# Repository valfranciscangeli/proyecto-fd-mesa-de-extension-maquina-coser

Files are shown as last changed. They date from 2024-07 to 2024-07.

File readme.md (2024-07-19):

# Proyecto de Mesa de Extensión para Máquina de Coser Casera

Este repositorio contiene el proyecto final del curso de Fabricación Digital. Se diseñó una mesa de extensión específicamente para la máquina de coser casera Janome Sakura 95.

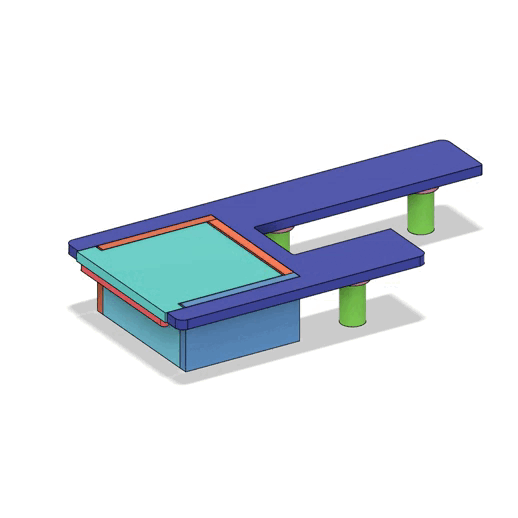
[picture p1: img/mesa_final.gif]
mesa completa


Las explicaciones sobre las piezas se basan en el documento `Piezas.pdf`, que muestra el número de pieza de cada parte del diseño.

## Resultado
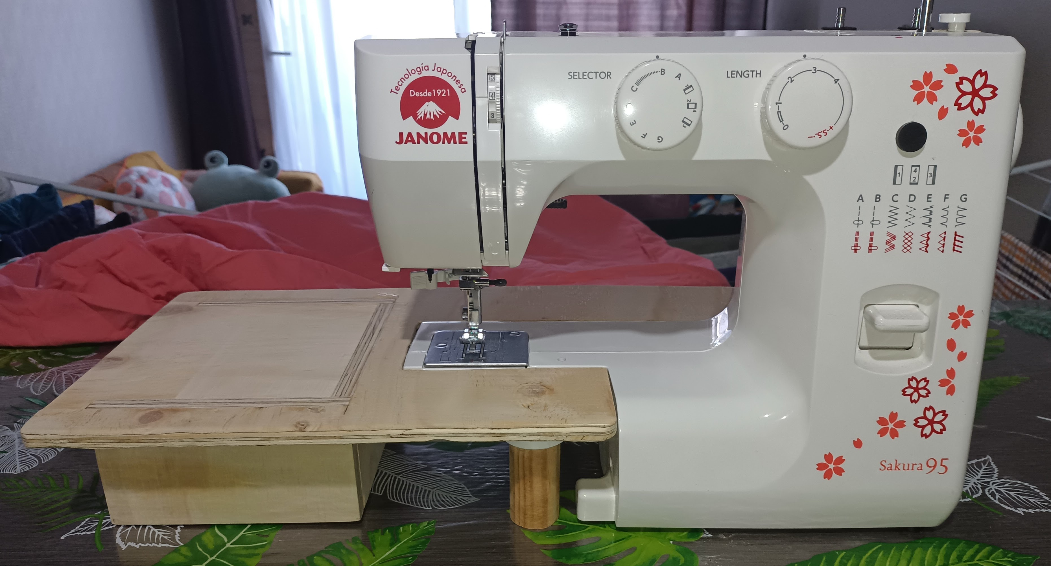
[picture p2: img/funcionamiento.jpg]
adaptador


## Archivos del Proyecto

En el repositorio se encuentran las siguientes carpetas y archivos:

- **origen**
  - **ensamble**
    - `proyecto_final`: archivo del ensamble final que referencia al resto de archivos.
    - **ensamble_cajon**: carpeta que contiene imágenes que muestran cómo se acoplan las piezas del cajón.
  - **fdm**: contiene los archivos de las piezas que se fabricaron con impresión 3D
    - **adaptador pata**: carpeta que contiene los archivos de la pieza número 8
    - **tirador**: carpeta que contiene los archivos de la pieza número 9
  - **img**: carpeta con archivos de imágenes usadas en este documento.
  - **router_cnc**: contiene los archivos de las piezas fabricadas por corte en router CNC
    - **cajon bottom**: carpeta que contiene los archivos de la pieza número 2
    - **cortes**: carpeta que contiene archivos de corte de las piezas del cajón base
    - **frontal**: carpeta que contiene los archivos de la pieza número 4
    - **lado 1**: carpeta que contiene los archivos de la pieza número 1
    - **lado 2**: carpeta que contiene los archivos de la pieza número 6
    - **mesa top**: carpeta que contiene los archivos de la pieza número 7
    - **posterior**: carpeta que contiene los archivos de la pieza número 3
    - **tapa**: carpeta que contiene los archivos de la pieza número 5
  - `Piezas.pdf`: archivo que muestra el número y tabla de piezas generada por el software Fusion360.

## Diseño

Se realizó el diseño del proyecto en el software Fusion 360. Los archivos se encuentran ordenados en las carpetas descritas anteriormente.

Se diseñó una mesa a medida de la máquina de coser Janome Sakura 95. El diseño contempla un cajón en la base que permite guardar accesorios de la máquina e implementos de costura.

Se numeran las piezas como sigue:

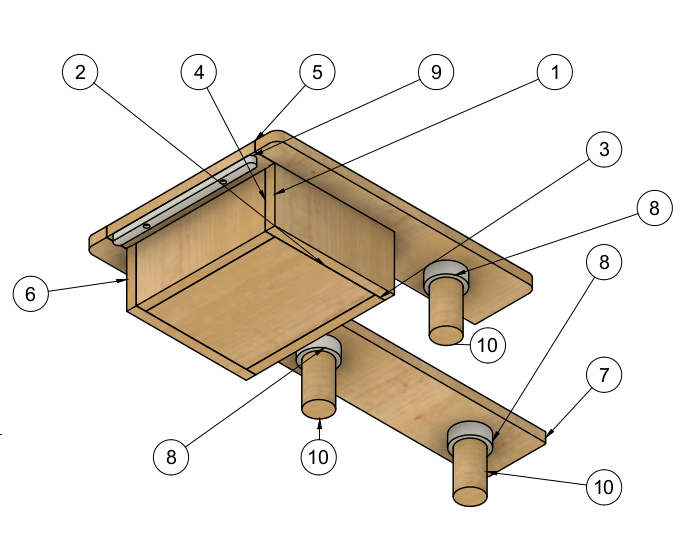
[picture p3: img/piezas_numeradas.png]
Tabla de piezas, materiales y procesos


## Piezas, Materiales y Procesos de Fabricación

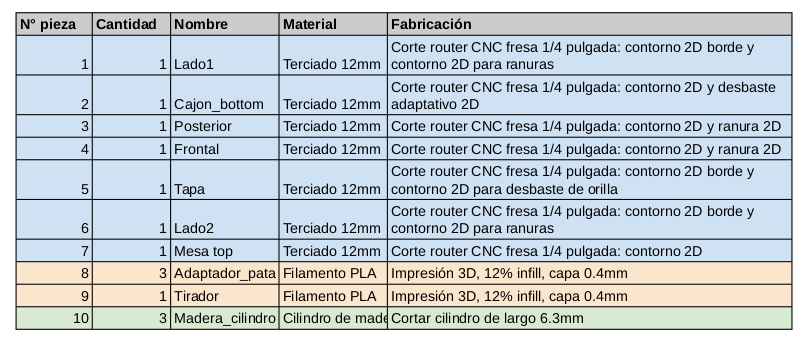
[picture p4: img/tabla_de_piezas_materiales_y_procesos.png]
Tabla de piezas, materiales y procesos


## Costos

Para realizar toda la estructura de la mesa se necesita:
- Una plancha de terciado de 12mm. Se necesita solo la mitad de la plancha estándar de 1,2x2,4m. El valor aproximado es de <a href="https://www.imperial.cl/terciados/terciado-estructural-12mm-120x240mt/product/76017">17.990 CLP</a>.
- 5 tornillos de 3x10mm. Un pack de 20 unidades costó 750 CLP.
- Filamento PLA. Las 4 piezas impresas en 3D utilizan 41g de filamento en total. Calculando en base a la referencia de <a href="https://cicla3d.cl/products/cicla-pla?variant=46081855357178">12.390 CLP</a> por Kg, el costo total de la impresión es de 508 CLP.
- Cola fría de madera, como pegamento. Se utiliza una cantidad muy pequeña, pero un sachet de 500g se encuentra a <a href="https://www.idepal.cl/cola-fria-doy-pack-500gr">1.990 CLP</a>.
- Barra de madera (cilindro) de 30mm. Se utilizó en total menos de 25cm en total de la barra. La única referencia de precio encontrada fue de de 2 barras de 30mmx1mt a <a href="https://articulo.mercadolibre.cl/MLC-536082012-barras-de-madera-de-coihue-lisas-30mm-x-1mt-2-u-_JM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">12.800 CLP</a>, sin embargo, se puede reutilizar un palo de escoba o cortina (mi caso) o imprimir la pieza en 3D.

## Ensamble

El ensamble general se encuentra en el archivo de `proyecto_final`.

Paso a paso:
1. Ensamblar la caja base uniendo con cola fría las piezas 1, 2, 3, 4 y 6. Deben calzar las ranuras en los bolsillos. Se adjuntan distintas vistas del proceso.
Vista superior 1.
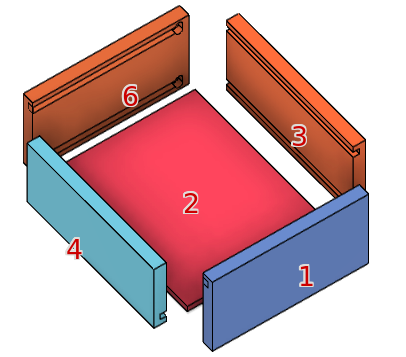
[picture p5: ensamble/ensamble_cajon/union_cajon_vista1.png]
Unión de piezas de cajón base. Vista superior 1.

Vista superior 2.
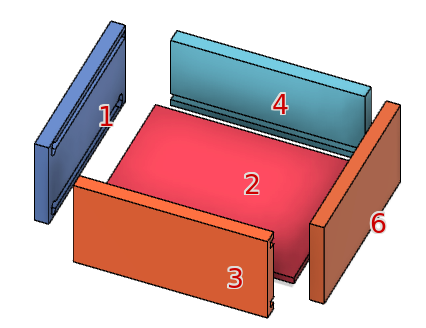
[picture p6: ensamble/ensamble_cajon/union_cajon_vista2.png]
Unión de piezas de cajón base. Vista superior 2.

Vista inferior.
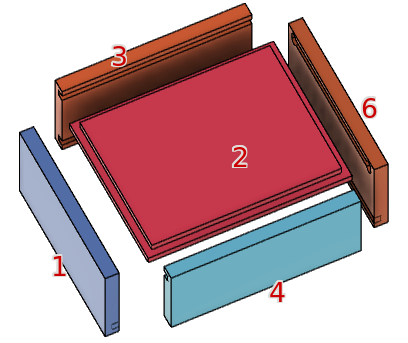
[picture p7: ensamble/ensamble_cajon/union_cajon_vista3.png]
Unión de piezas de cajón base. Vista inferior.

2. Unir a la parte superior de la caja base del paso 1 la pieza 7. Se puede pegar solo con cola fría o agregar clavos (en mi caso no fue necesario).
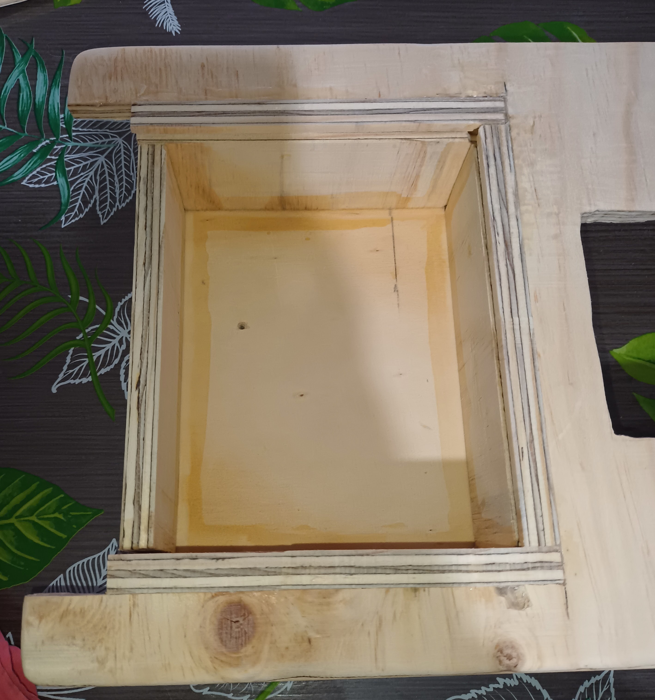
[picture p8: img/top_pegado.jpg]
Pegado de top


3. Unir con tornillos de 3x10mm la pieza 9 a la parte inferior de la pieza 5.
El tirador debe ir con el orificio de 2 profundidades hacia arriba, para ahí insertar el tornillo.
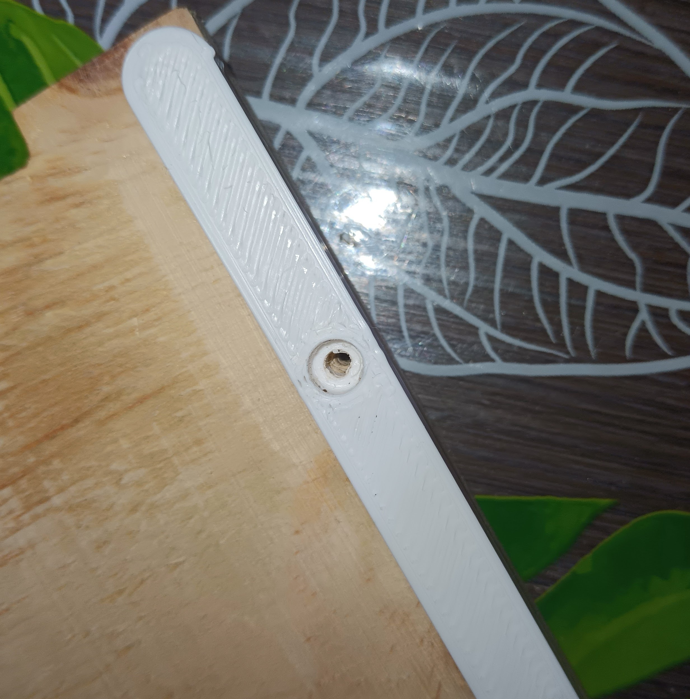
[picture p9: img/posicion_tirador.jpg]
Unión de tirador

Tornillo 3x10mm.
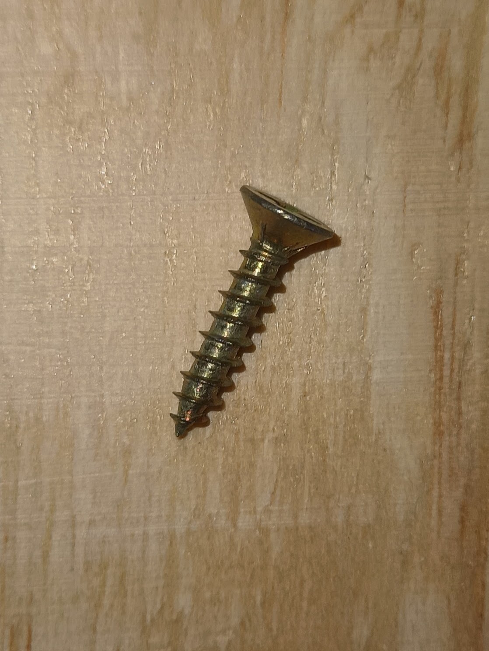
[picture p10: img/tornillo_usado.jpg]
Tornillo usado

Así queda:
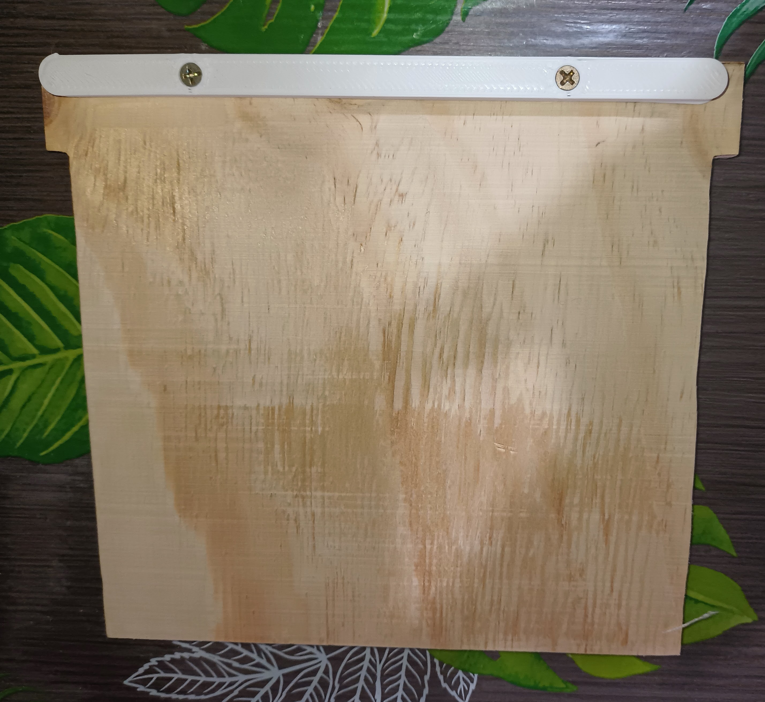
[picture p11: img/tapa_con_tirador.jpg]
Tapa

4. Unir con tornillos de 3x10mm las piezas 8 a la parte inferior de la pieza 7, siguiendo la distancia del diseño del proyecto. Cortar un cilindro de madera de 30mm de diámetro en 3 piezas de largo 6.3mm, para utilizar como pieza 10. Luego insertar estas piezas en cada adaptador (pieza 8).
Adaptador atornillado:
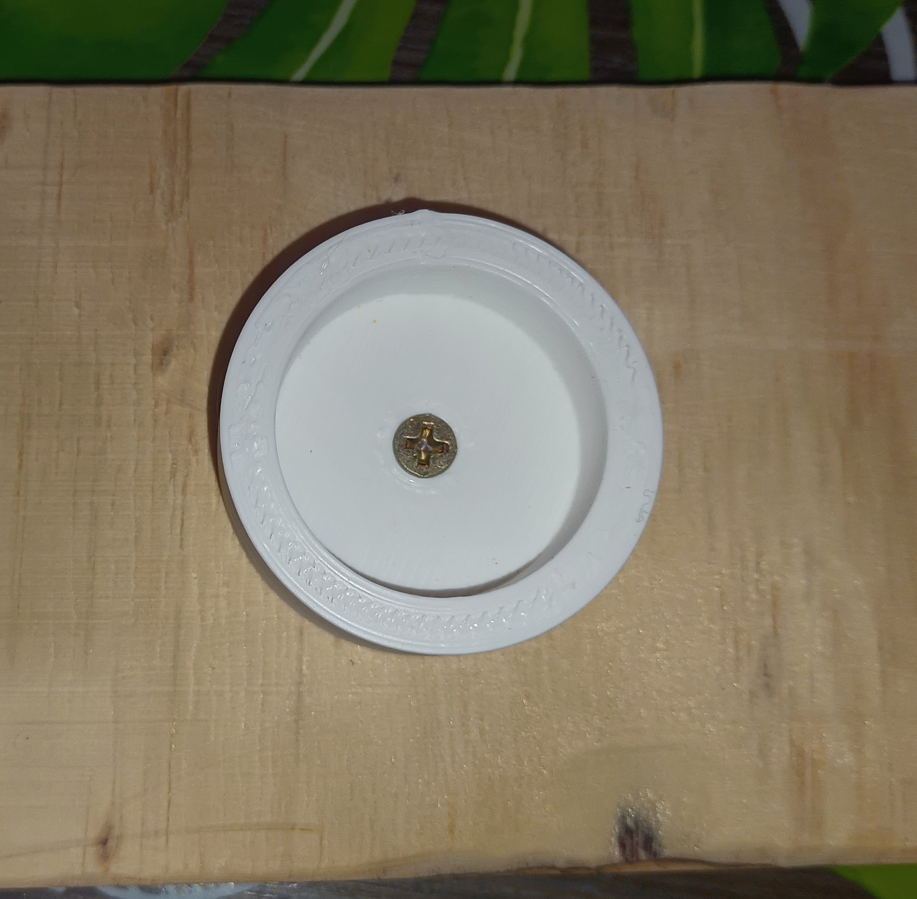
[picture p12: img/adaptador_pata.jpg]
Adaptador

Agregar pieza 10:
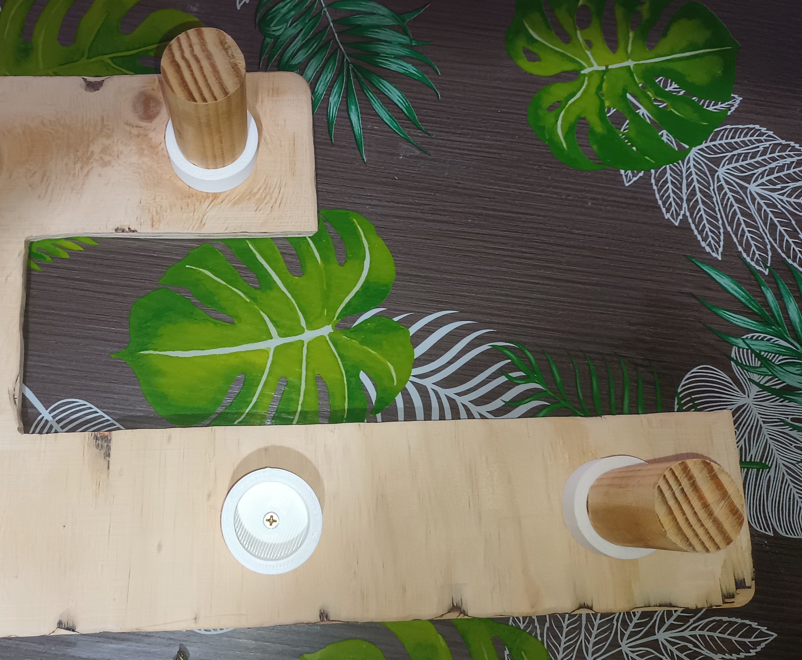
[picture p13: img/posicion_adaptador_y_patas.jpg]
Adaptador

5. Deslizar la pieza 9 con la pieza 5 hacia abajo por las ranuras del cajón base armado en el paso 1.
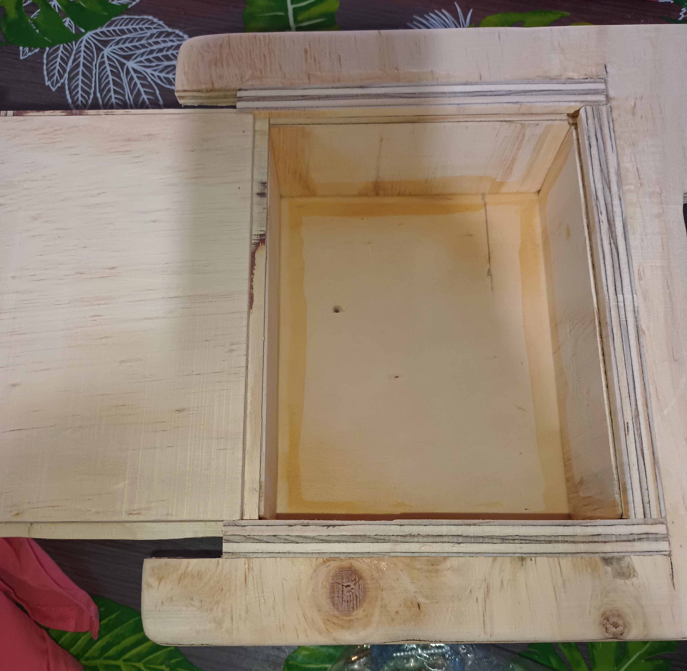
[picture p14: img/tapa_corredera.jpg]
Tapa

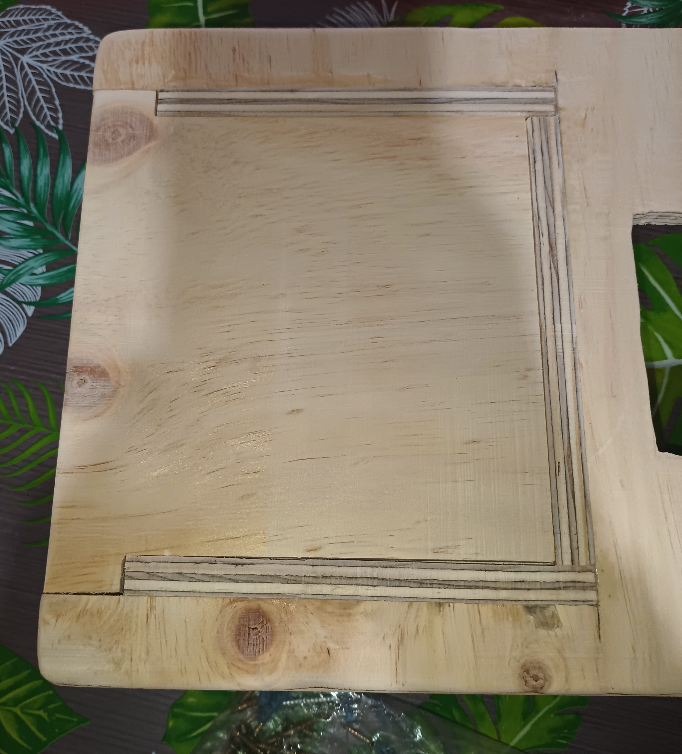
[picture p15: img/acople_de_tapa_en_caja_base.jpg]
Acople


6. Lijar toda la pieza con lija de madera hasta que la superficie sea suave, para no enganchar la tela.
7. Opcional: agregar bases de goma antideslizantes.
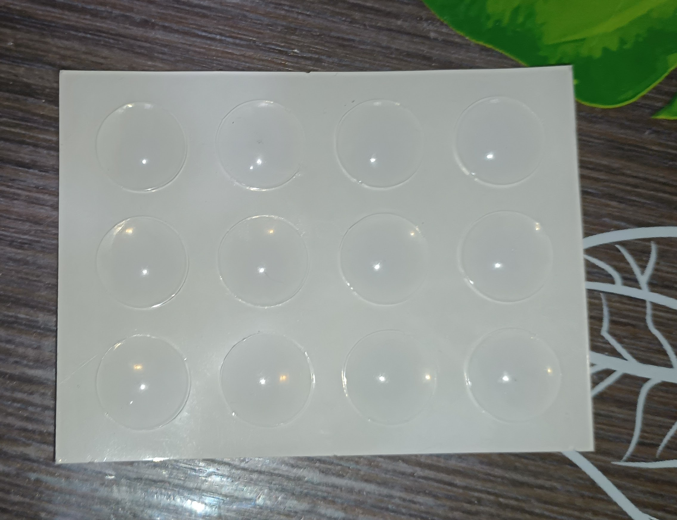
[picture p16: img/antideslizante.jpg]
Gomas antideslizantes

Patas:
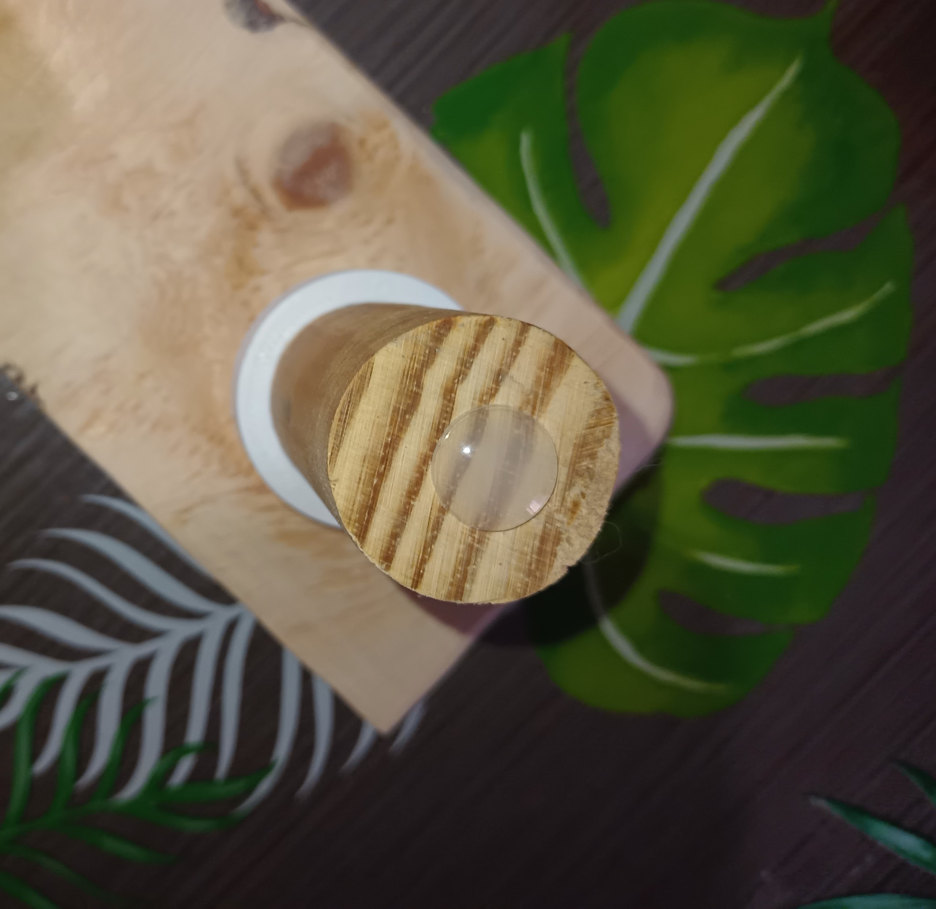
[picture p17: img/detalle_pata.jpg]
Patas

Cajón vista inferior:
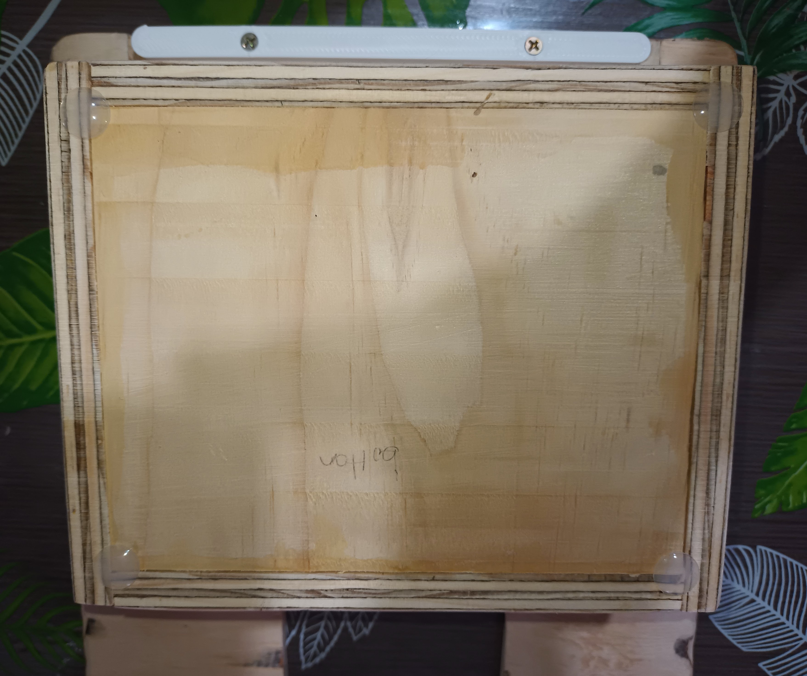
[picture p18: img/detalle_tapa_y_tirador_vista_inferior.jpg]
Cajón vista inferior


## Sugerencias para mejorar el proyecto
- Cortar la pieza 7 en una lámina de acrílico para tener una superficie completamente lisa y una mesa más estética.
- Agregar un soporte para cono de hilo de tamaño normal en la parte trasera de la pieza 7.

## Material Extra

En la carpeta img se adjuntan imágenes del proceso incluyendo las que se encuentran en este archivo.

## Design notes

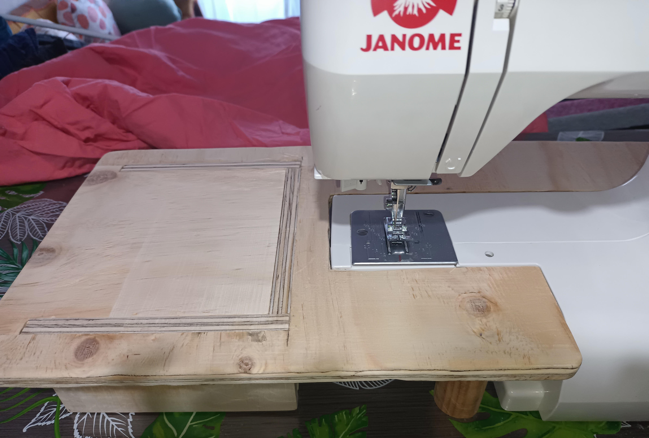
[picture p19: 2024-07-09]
img/detalle_acople.jpg

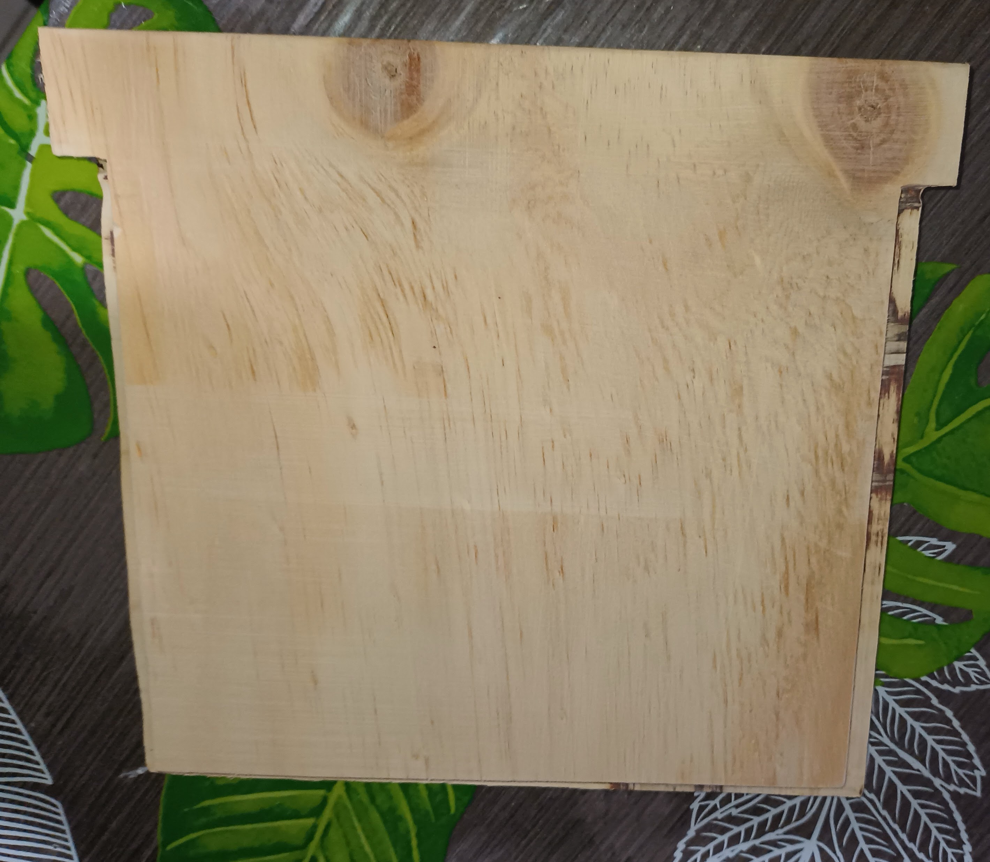
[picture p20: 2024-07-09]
img/tapa.jpg

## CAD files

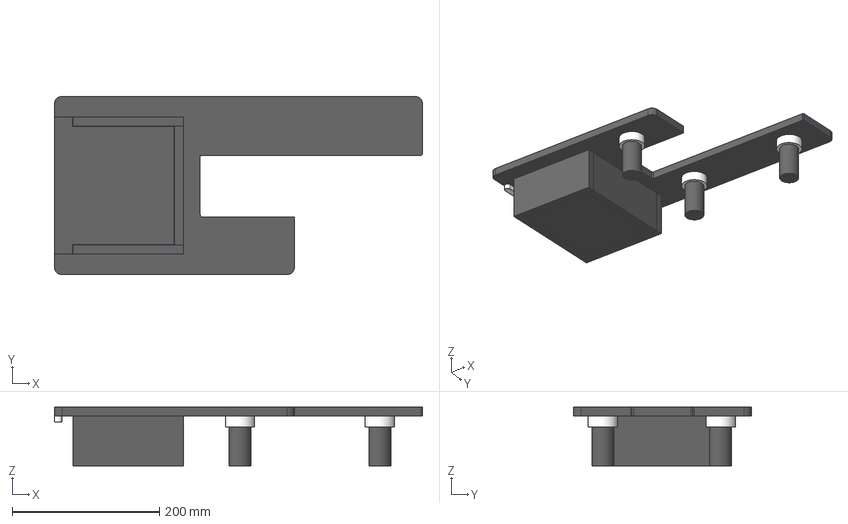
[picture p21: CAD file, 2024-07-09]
ensamble/proyecto_final/ProyectoFinal v28.step
500.0 x 242.0 x 80.0 mm
lado1
cajon_bottom
posterior
frontal
tapa
lado2
mesa top
adaptador_pata x 3
tirador
madera_cilindro x 3

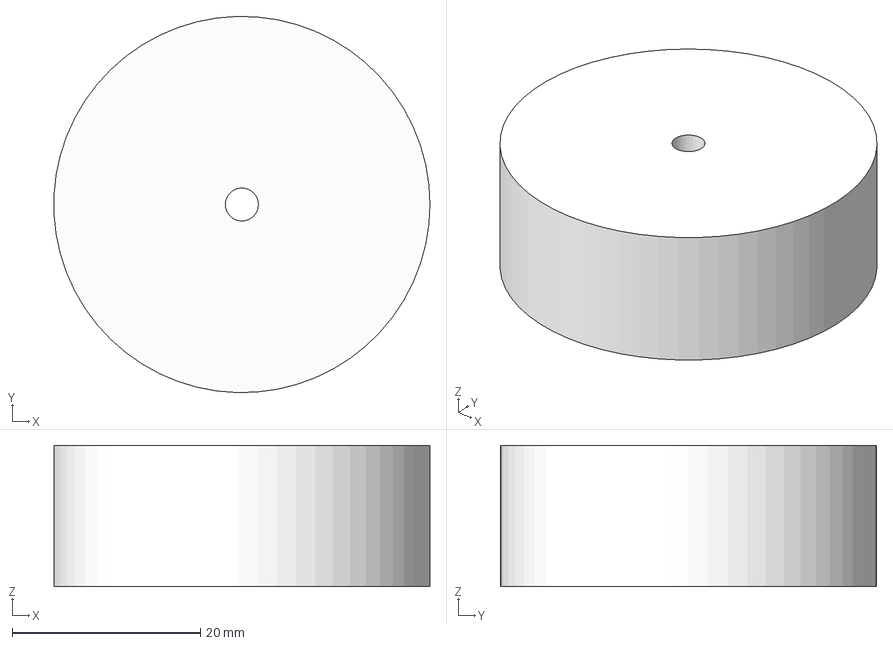
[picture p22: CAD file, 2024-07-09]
fdm/adaptador pata/adaptador_pata v7.step
40.0 x 40.0 x 15.0 mm

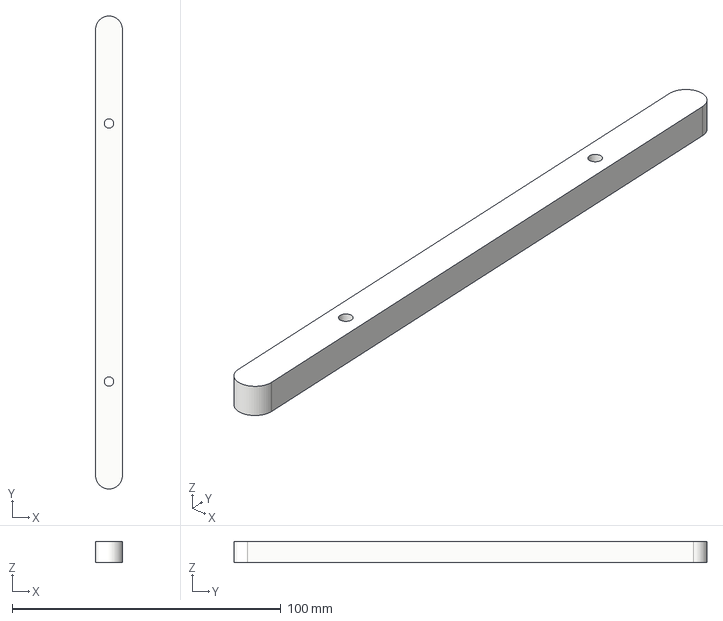
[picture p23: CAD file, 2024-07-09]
fdm/tirador/tirador v1.step
10.0 x 176.1 x 8.00 mm

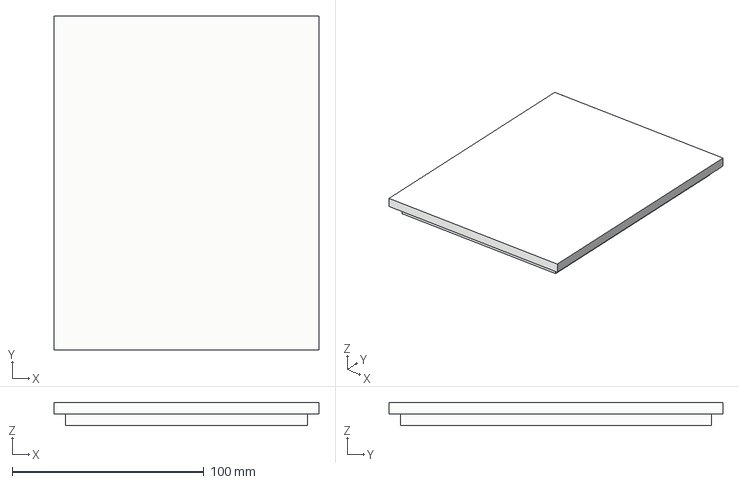
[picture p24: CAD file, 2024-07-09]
router_cnc/cajon bottom/cajon_bottom v3.step
138.0 x 174.0 x 12.0 mm

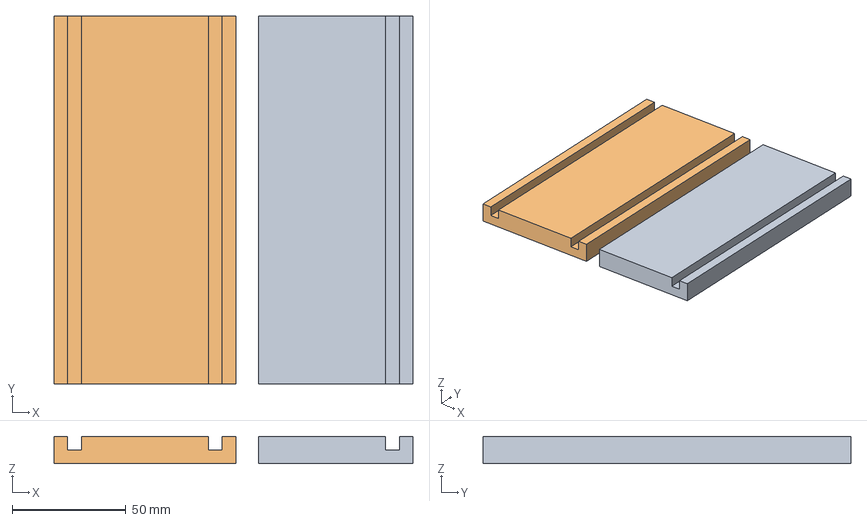
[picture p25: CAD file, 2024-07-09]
router_cnc/cortes/corte 1/corte cajón v11.step
158.0 x 162.0 x 12.0 mm
frontal
posterior

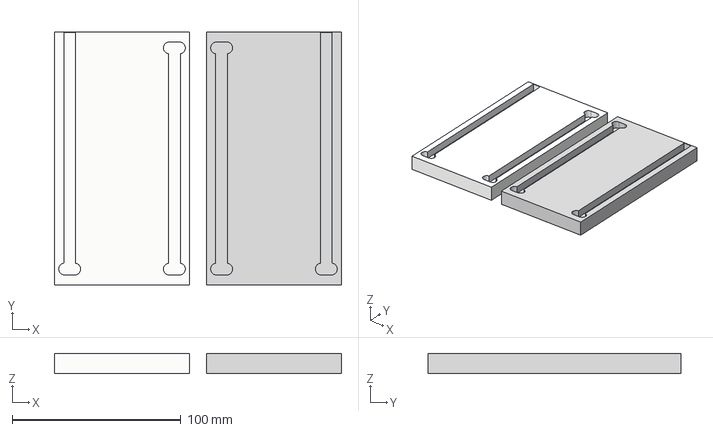
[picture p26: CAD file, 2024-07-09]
router_cnc/cortes/corte 3/corte cajón 3 v7.step
170.0 x 150.0 x 12.0 mm
lado1
lado2

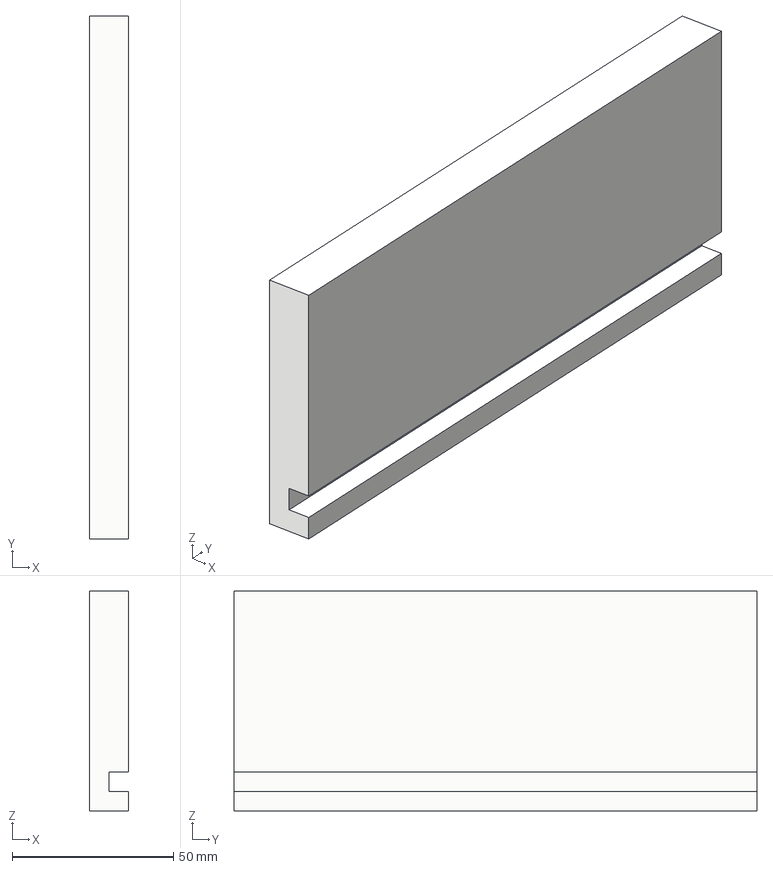
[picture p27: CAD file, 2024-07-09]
router_cnc/frontal/frontal v1.step
12.0 x 162.0 x 68.0 mm

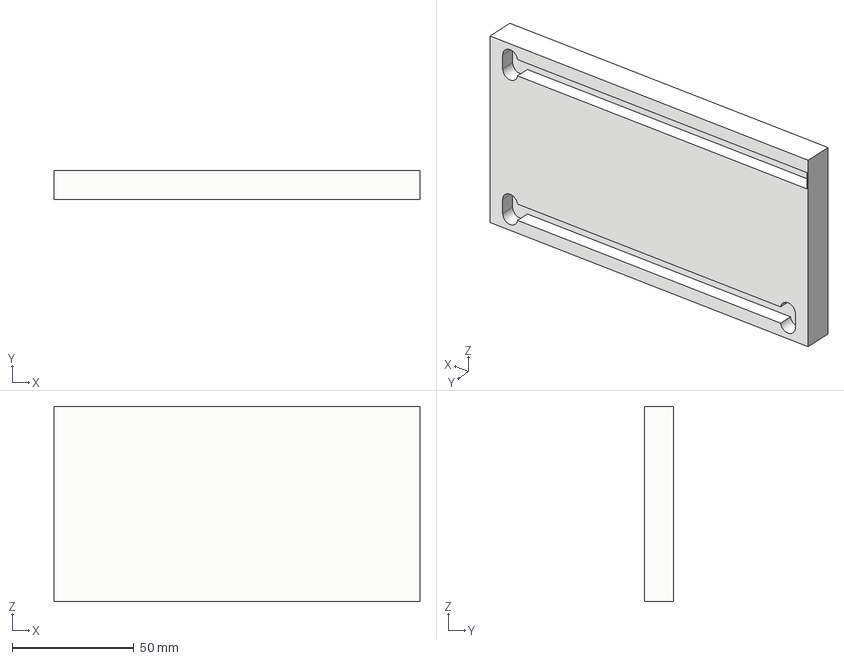
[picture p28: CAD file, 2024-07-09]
router_cnc/lado 1/lado1 v4.step
150.0 x 12.0 x 80.0 mm

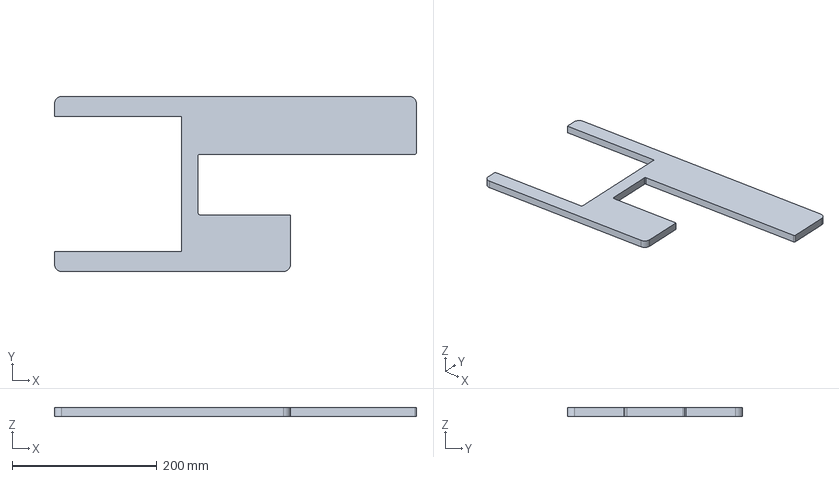
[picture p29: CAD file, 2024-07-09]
router_cnc/mesa top/mesa top v9.step
500.0 x 242.0 x 12.0 mm

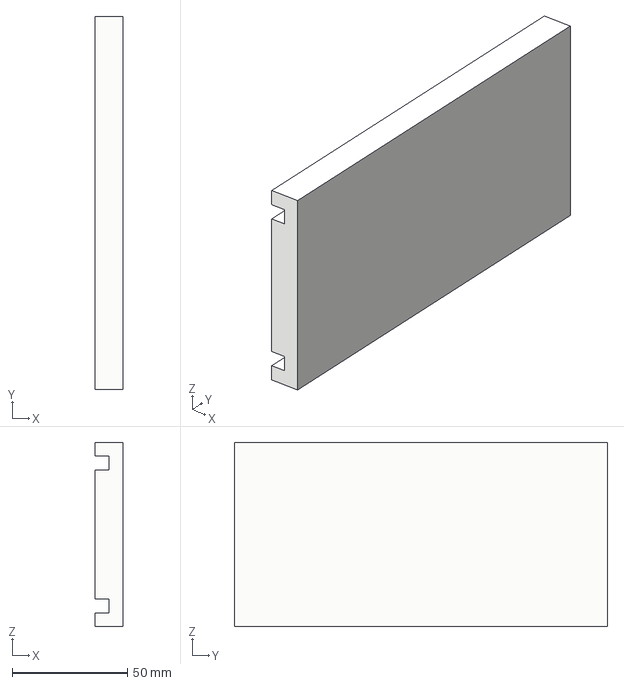
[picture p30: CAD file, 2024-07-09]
router_cnc/posterior/posterior v1.step
12.0 x 162.0 x 80.0 mm

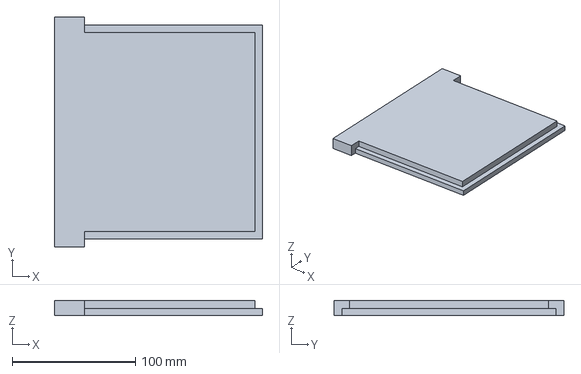
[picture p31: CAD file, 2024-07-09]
router_cnc/tapa/tapa v6.step
168.5 x 186.1 x 12.0 mm

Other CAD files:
router_cnc/cortes/corte 2/corte cajón 2 v13.step
router_cnc/lado 2/lado2 v5.step
ensamble/proyecto_final/ProyectoFinal v28.f3z
fdm/adaptador pata/adaptador_pata v7.f3d
fdm/tirador/tirador v1.f3d
router_cnc/cajon bottom/cajon_bottom v3.f3d
router_cnc/cortes/corte 1/corte cajón v11.f3z
router_cnc/cortes/corte 2/corte cajón 2 v13.f3z
router_cnc/cortes/corte 3/corte cajón 3 v7.f3z
router_cnc/frontal/frontal v1.f3d
router_cnc/lado 1/lado1 v4.f3d
router_cnc/lado 2/lado2 v5.f3d
router_cnc/mesa top/mesa top v9.f3d
router_cnc/posterior/posterior v1.f3d
router_cnc/tapa/tapa v6.f3d

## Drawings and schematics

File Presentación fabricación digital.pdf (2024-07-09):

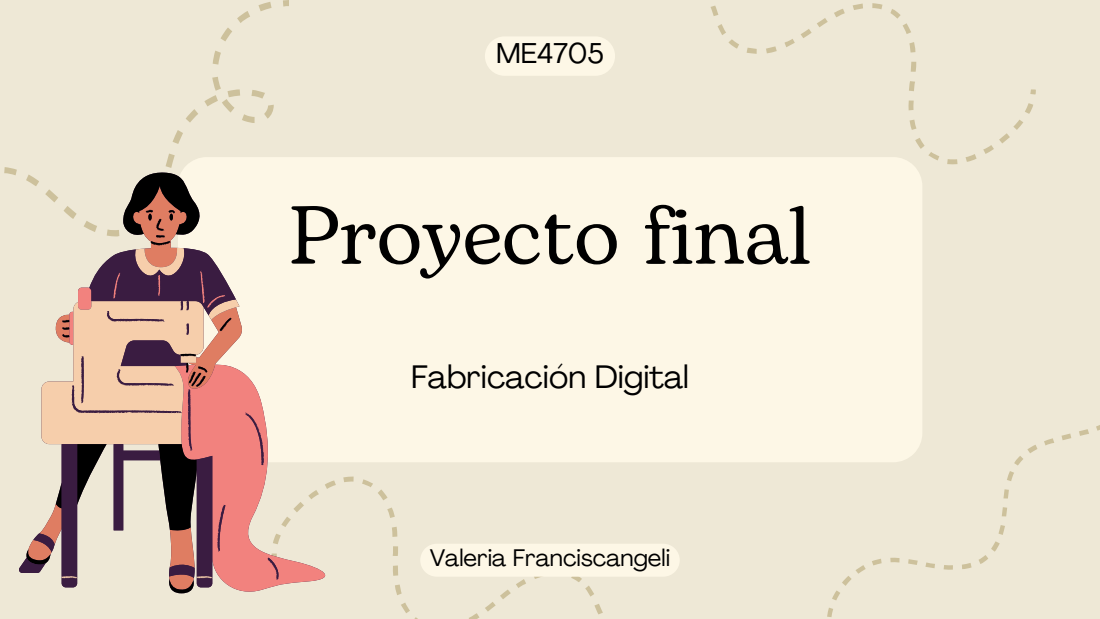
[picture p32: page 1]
Proyecto final; Fabricación Digital; Valeria Franciscangeli

# Problema

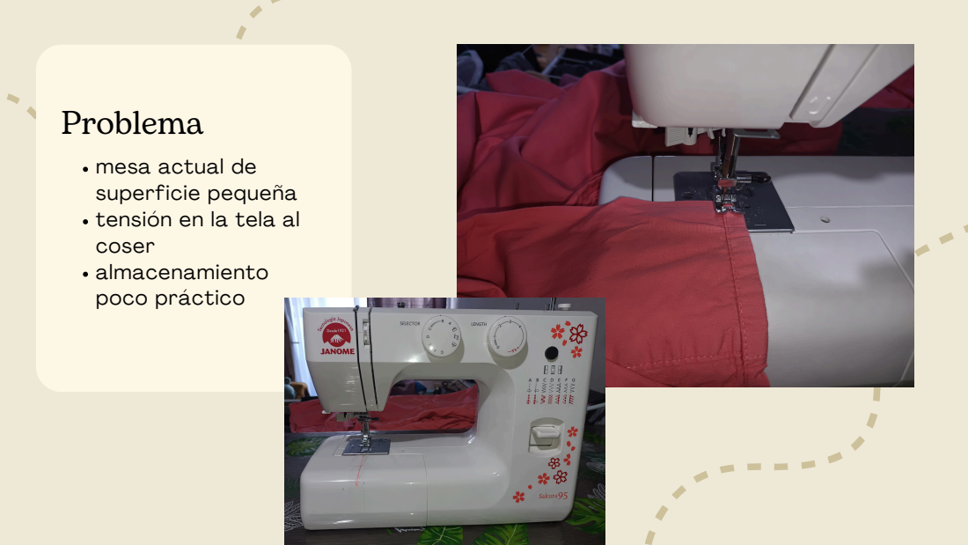
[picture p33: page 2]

mesa actual de
superficie pequeña
tensión en la tela al
coser
almacenamiento
poco práctico

# Diseño inicial

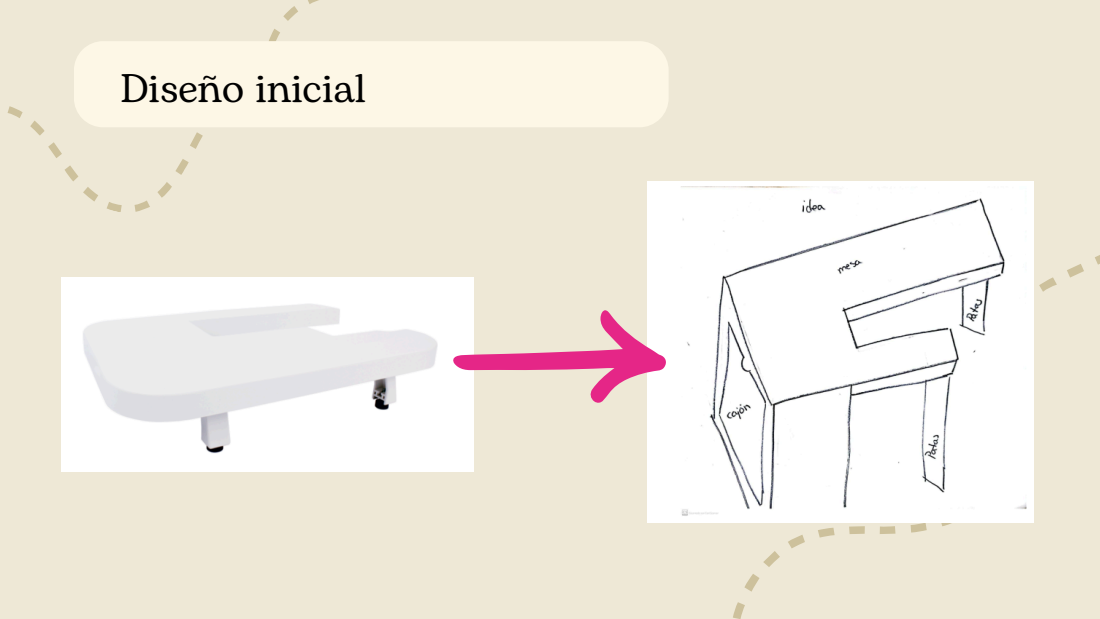
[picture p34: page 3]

# Diseño final

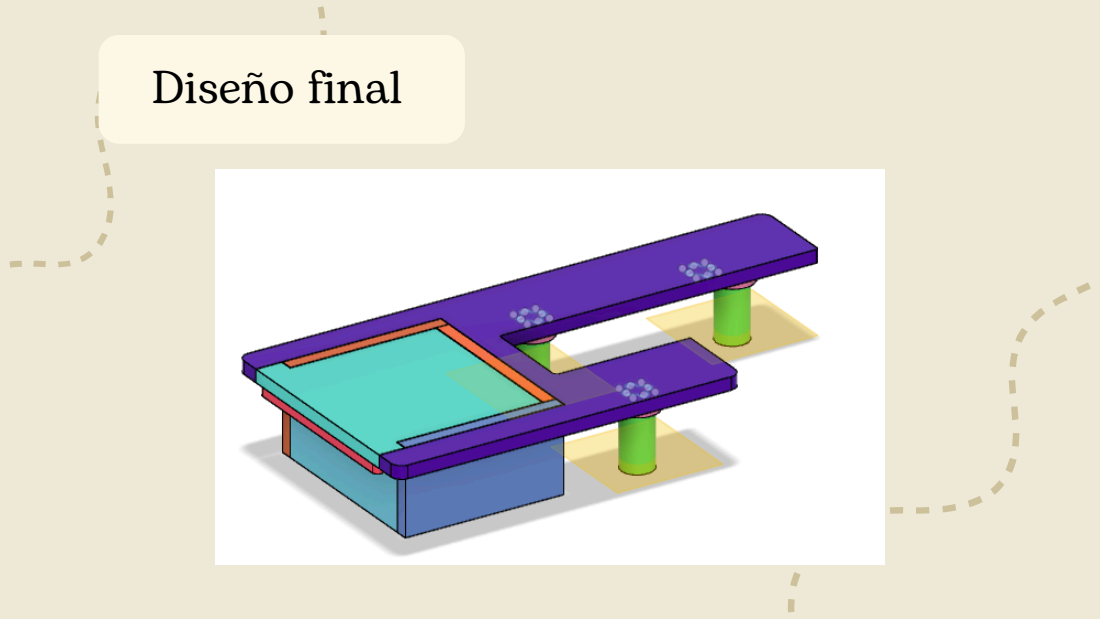
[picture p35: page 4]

Fabricación | Piezas

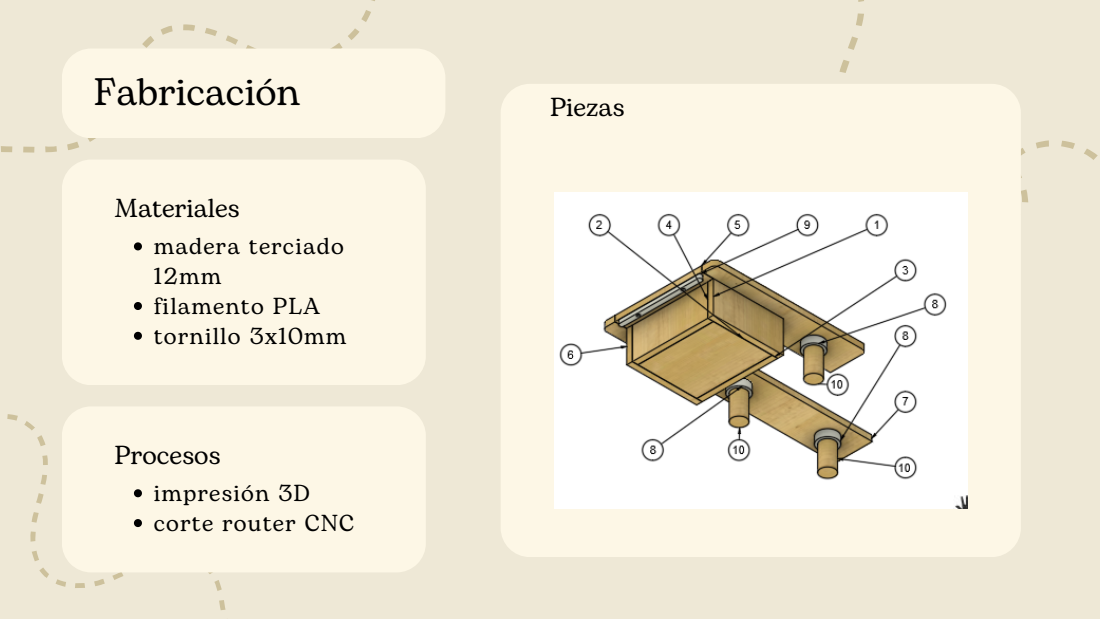
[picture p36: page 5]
madera terciado 12mm filamento PLA tornillo 3x10mm; Materiales

Procesos
impresión 3D
corte router CNC

# Fabricación

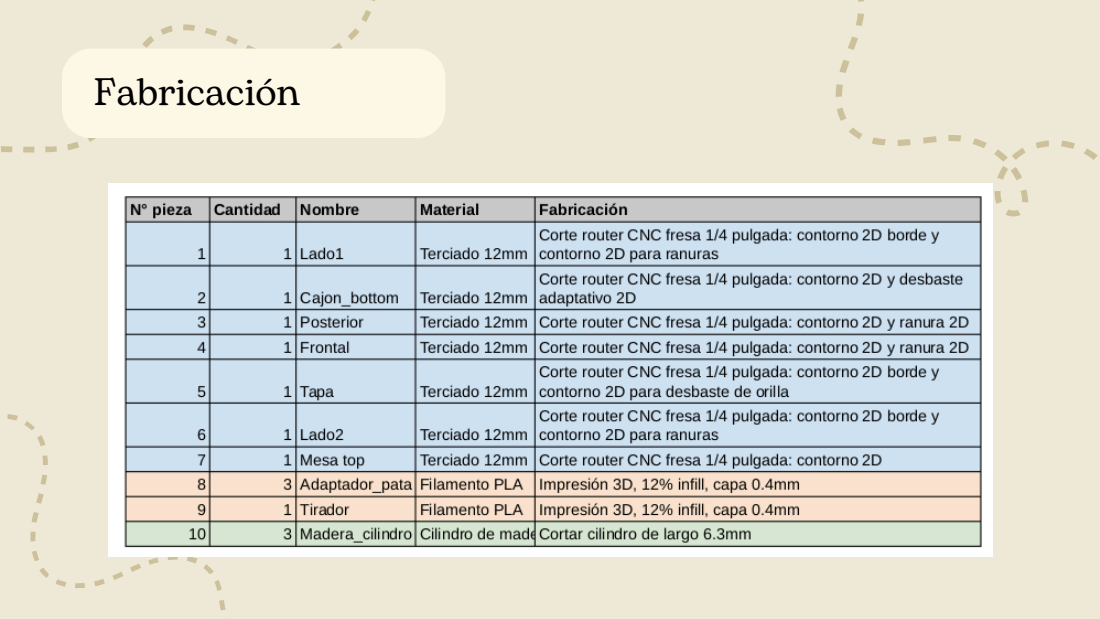
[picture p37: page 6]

# Resultado

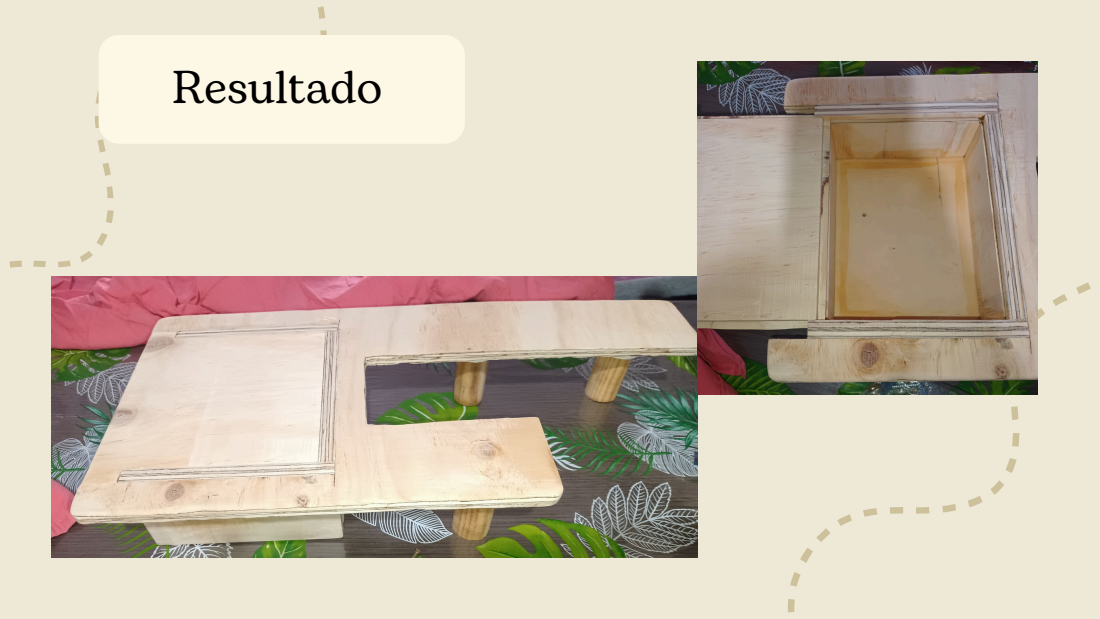
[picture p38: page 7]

# Funcionamiento

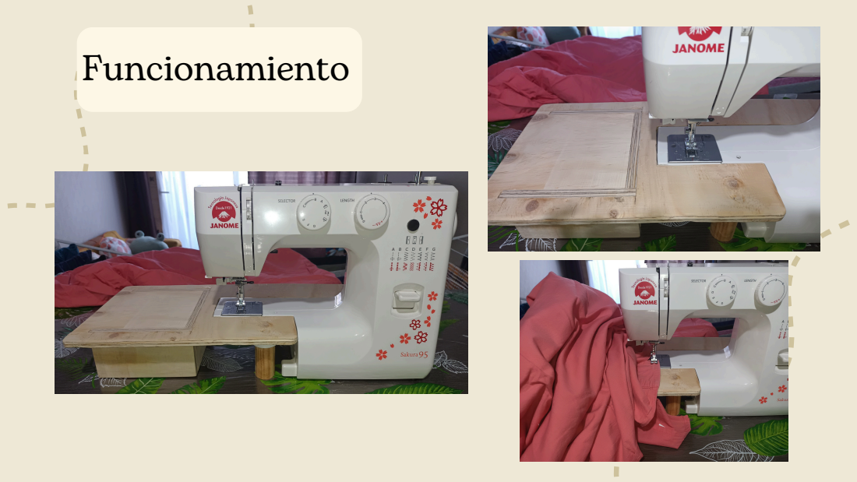
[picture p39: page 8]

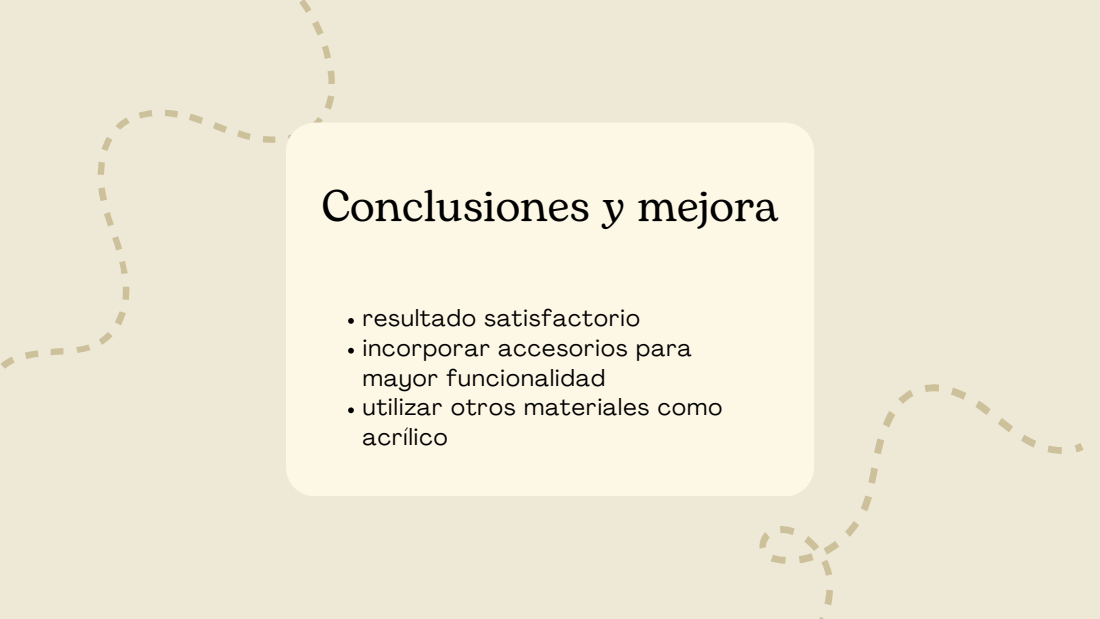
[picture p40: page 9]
Conclusiones y mejora

resultado satisfactorio
incorporar accesorios para
mayor funcionalidad
utilizar otros materiales como
acrílico

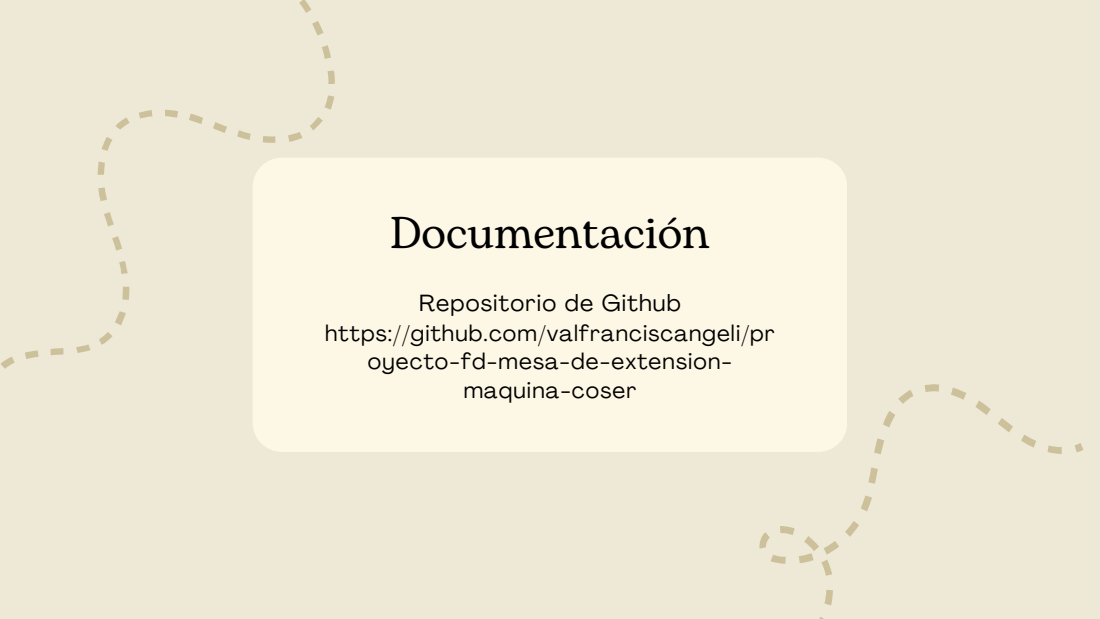
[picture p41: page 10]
Documentación; maquina-coser

Repositorio de Github

https://github.com/valfranciscangeli/pr
oyecto-fd-mesa-de-extension-

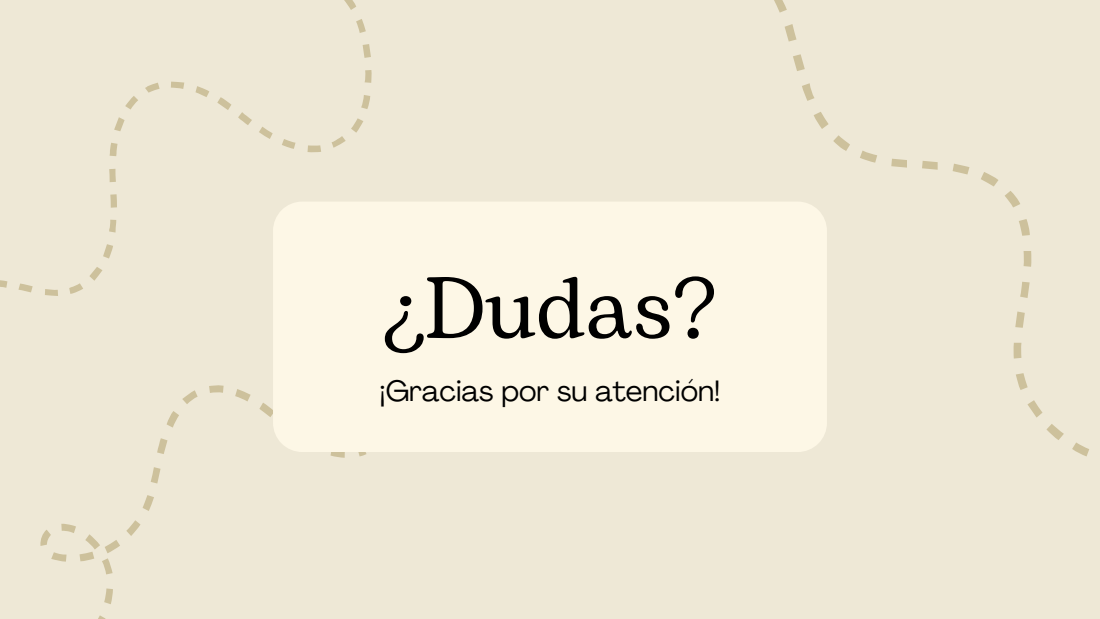
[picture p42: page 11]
¿Dudas?

¡Gracias por su atención!

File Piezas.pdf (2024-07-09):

2 | 4 | 5 | 9 | 1

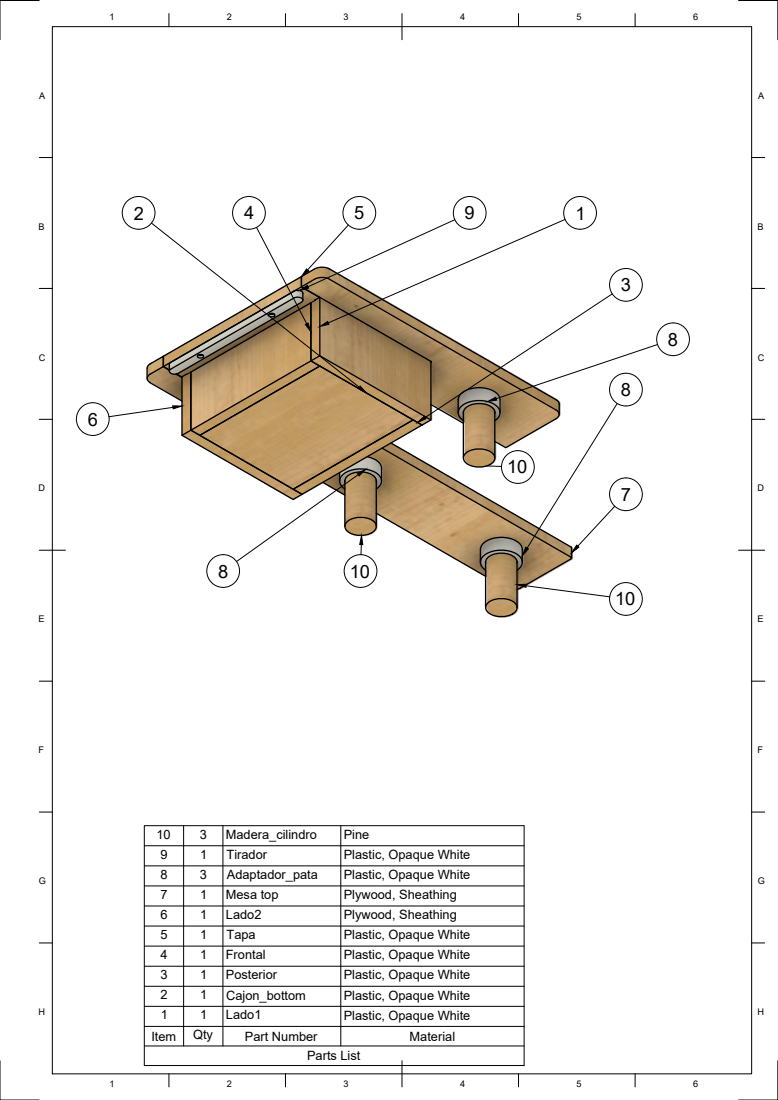
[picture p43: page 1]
Parts List; Item; Qty; Part Number; Material; Lado1; Plastic, Opaque White; Cajon_bottom; Posterior; Frontal; Tapa; Lado2; Plywood, Sheathing; Mesa top; Adaptador_pata; Tirador; Madera_cilindro; Pine

10 | 8 | 7 4 | 6

6 ABCDEFGH; ABCDEFG; Parts List; Item; Qty; Part Number; Material 1; Lado1; Plastic,; Opaque; White 2; Cajon_bottom; White 3; Posterior; White 4; Frontal; White 5; Tapa; White 6; Lado2; Plywood,; Sheathing 7; Mesa top; Sheathing 8; Adaptador_pata; White 9; Tirador; Opaque White; Madera_cilindro; Pine 21953

N° pieza | Cantidad | Nombre | Material | Fabricación
1 | 1 | Lado1 | Terciado 12mm | Corte router CNC fresa 1/4 pulgada: contorno 2D borde y contorno 2D para ranuras
2 | 1 | Cajon_bottom | Terciado 12mm | Corte router CNC fresa 1/4 pulgada: contorno 2D y desbaste adaptativo 2D
3 | 1 | Posterior | Terciado 12mm | Corte router CNC fresa 1/4 pulgada: contorno 2D y ranura 2D
4 | 1 | Frontal | Terciado 12mm | Corte router CNC fresa 1/4 pulgada: contorno 2D y ranura 2D
5 | 1 | Tapa | Terciado 12mm | Corte router CNC fresa 1/4 pulgada: contorno 2D borde y contorno 2D para desbaste de orilla
6 | 1 | Lado2 | Terciado 12mm | Corte router CNC fresa 1/4 pulgada: contorno 2D borde y contorno 2D para ranuras
7 | 1 | Mesa top | Terciado 12mm | Corte router CNC fresa 1/4 pulgada: contorno 2D
8 | 3 | Adaptador_pata | Filamento PLA | Impresión 3D, 12% infill, capa 0.4mm
9 | 1 | Tirador | Filamento PLA | Impresión 3D, 12% infill, capa 0.4mm
10 | 3 | Madera_cilindro | Cilindro de madeCortar cilindro de largo 6.3mm

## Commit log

2024-07-09 archivos finales
    [ProyectoFinal v28.f3z, ProyectoFinal v28.step, adaptador_pata v7.f3d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]
2024-07-09 imagenes y listado de piezas
2024-07-09 imganes de union
    [ProyectoFinal v28.f3z, ProyectoFinal v28.step]
